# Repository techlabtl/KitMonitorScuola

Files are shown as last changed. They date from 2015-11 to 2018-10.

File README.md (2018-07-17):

## KIT CONSUMARE DI MENO versione2018

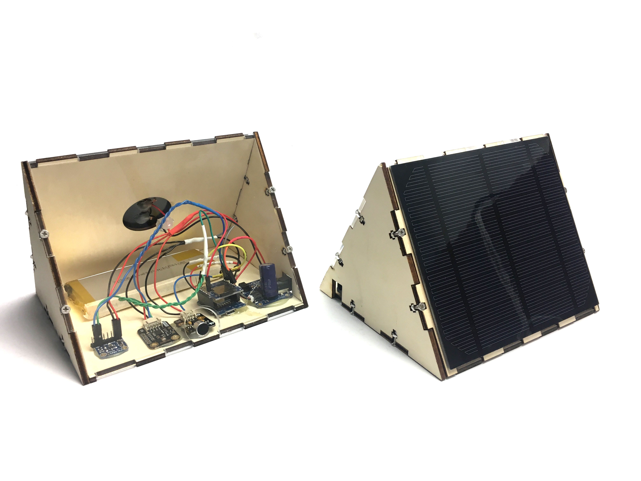
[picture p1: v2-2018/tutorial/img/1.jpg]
Screenshoot


## COMPONENTI
* Wemos
* MicroSD Shield (Optional)
* sd card (Optional)
* BME680
* TSL2561
* ANALOG LIGHT SENS BREAKOUT BOARD

## PINMAP
#### SENSORI I2C -> WEMOS
* sda -> D2
* scl -> D1
* vin -> 3.3V
* gnd -> GND
#### Analog light -> WEMOS
* vcc -> 3.3V
* gnd -> GND
* out -> A0

## Descrizione
la wemos espone una rete wifi chiamata __"Kit Monitoraggio"__

all'indirizzo __192.168.4.1 è presente un webserver che comunica i dati istantanei e quelli medi rilevati da quando la wemos è stata accesa l'ultima volta

## Backup
aggiungendo una shield wemos SD e una scheda SD, vengono automaticamente registrati i dati raccolti.
per risparmiare risorse viene salvata solo la media dei dati degli ultimi 10 minuti.

## Customization
* modificando la variabile __LIGHT_THRESHOLD__ è possibile indicare la soglia sopra la quale la luce viene considerata accesa
* modificando la variabile __SAVE_TIME__ è possibile cambiare la frequenza con cui vengono salvati i dati su sd
* modificando la variabile __SENSOR_TIME__ è possibile cambiare la frequenza con cui vengono letti i sensori
* modificando la variabile __*ssid__ è possibile cambiare il nome della rete wifi esposta

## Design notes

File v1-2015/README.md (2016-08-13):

# KitMonitorScuola
Repository del progetto "Impariamo a consumare di meno.." promosso da Gennaro Fanelli e Finanziato dal MIUR nel 2015.
Nella cartella **Tutorial** trovi le istuzioni per costruire il tuo kit di monitoraggio energertico e nella cartella **Kits** ci sono i file di configurazione dei kit attualmente montati e funzionanti.

Un breve indice:

 * [Istruzioni per comprare e costruirti da te il kit] (#sec1)
 * [Il codice da caricare sull'arduino YUN per leggere i sensori e testare il kit] (#sec2)
 * [Il tutorial per collegare il KIT alla wifi e mandare i dati a plot.ly] (#sec3)
 * [I grafici prodotti da una scuola partecipante al progetto] (#sec4)

### Istruzioni per comprare e costruire da te il kit 
All'interno della cartella [Assemblaggio](https://github.com/paolocavagnolo/KitMonitorScuola/tree/master/Tutorial/Assemblaggio) è presente la lista di materiale necessaria per la realizzazione del kit. Sono presenti anche tutti i link per gli acquisti da [Arduino.cc](https://www.arduino.cc/) e [SeeedStudio](http://www.seeedstudio.com/).

Si sottolinea che la prima scelta è stata quella del kit spagnolo [SmartCitizien](https://smartcitizen.me/)

Inoltre è presente il file per tagliare a laser la basetta e la copertura; da portare in qualsiasi Fablab o Makerspace. In zona si segnalano:
* [TechLab] (http://techlab.tl/)
* [FabLab Torino] (http://fablabtorino.org/)
* [FabLab Settimo] (http://www.fablabsettimo.org/)

Tutti gli altri componenti sono facilmente reperibili in ferramenta.

### Il codice da caricare sull'arduino YUN per leggere i sensori e testare il kit 
Una volta assemblato il kit sarà necessario caricare sopra l'arduino il codice necessario per testare i vari sensori. E' possibile comperare svariate tipologie di sensori e, una volta capito il meccanismo illustrato nella cartella [Configurazione](https://github.com/paolocavagnolo/KitMonitorScuola/tree/master/Tutorial/Configurazione), testarli ed utilizzarli.

### Il tutorial per collegare il KIT alla wifi e mandare i dati a plot.ly 
Il passo successivo è quello di collegare il kit ad internet in modo che possa comunicare con il servizio gratuito on-line [plot.ly](https://plot.ly/
Nella cartella [ConnessioneWifi](https://github.com/paolocavagnolo/KitMonitorScuola/tree/master/Tutorial/ConnessioneWifi) sono presenti i link con i tutorial specifici per ogni passaggio e i codici definitivi da caricare sulla scheda.

### I grafici prodotti da una scuola partecipante al progetto 

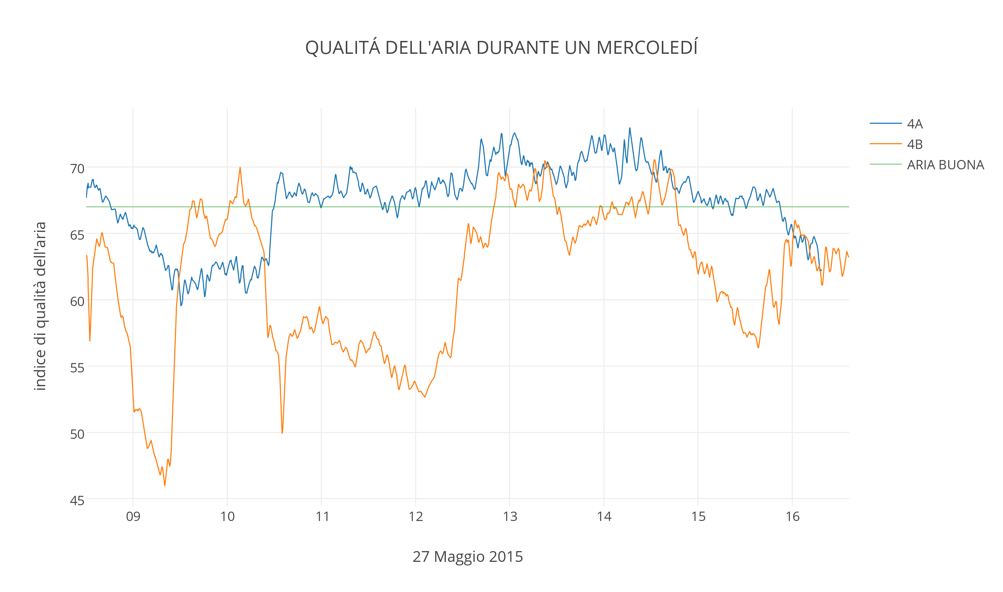
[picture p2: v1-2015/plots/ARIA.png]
Qualita' dell'aria


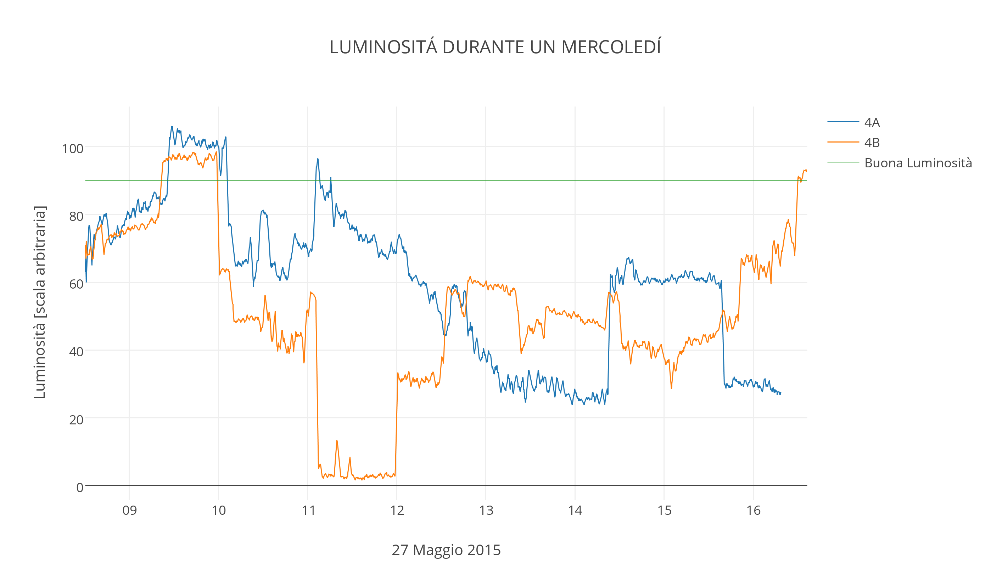
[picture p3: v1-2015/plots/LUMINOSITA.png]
Luminosita'


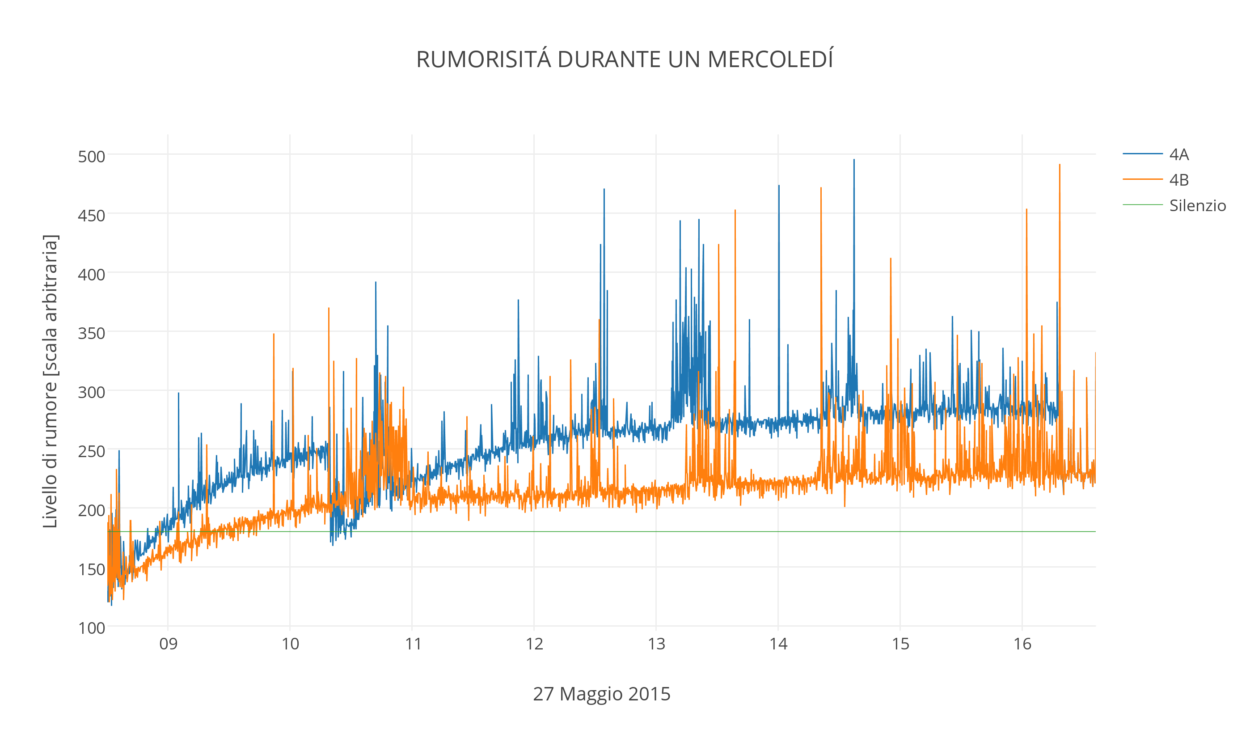
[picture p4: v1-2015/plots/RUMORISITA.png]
Rumorisita'


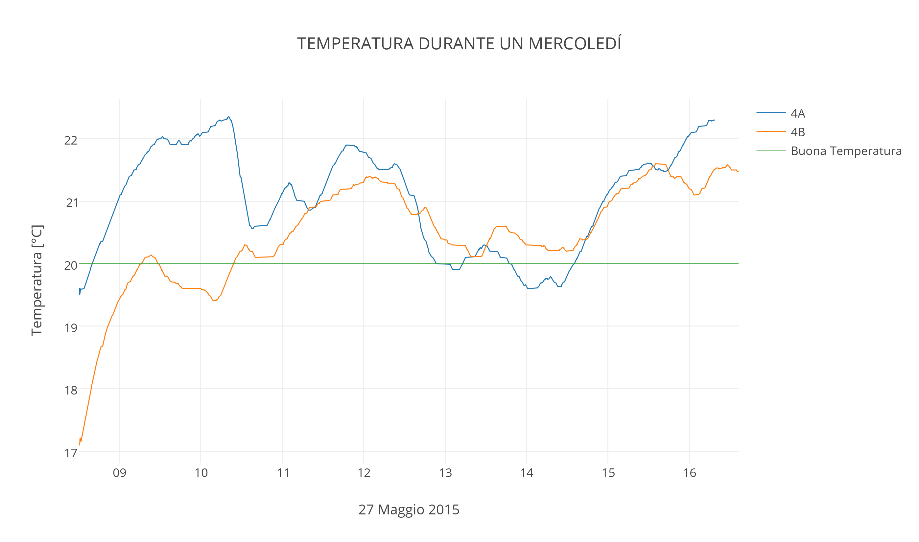
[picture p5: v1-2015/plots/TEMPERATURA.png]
Temperatura


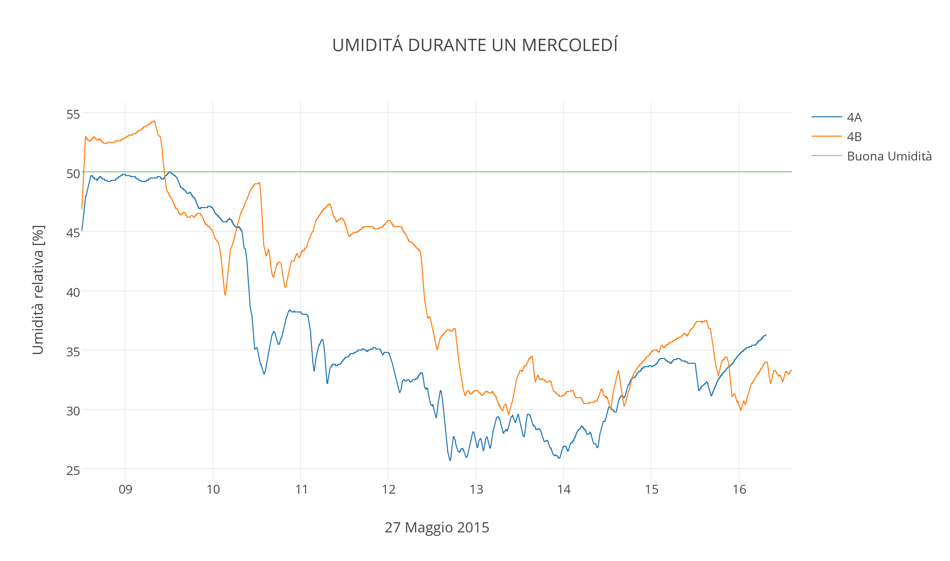
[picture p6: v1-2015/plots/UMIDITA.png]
Umidita'


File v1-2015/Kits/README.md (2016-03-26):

#Guida per la configurazione della yun per renderla un bel client per plotly

Bene, eccoci.
Questa guida raccoglie tutti i passaggi per poter configurare l'arduino YÚN, con i 5 sensori collegati.
L'idea di base è la seguente:

 - Il processore 32U4 presente sulla YÚN verrò fleshato con apposito codice e si occuperà di raccogliere i dati ogni X secondi e scriverli all'interno di due file:
    - **datalog.txt** dove verranno registrati per backup
    - **/collector/arduinoData** che rappresenta il buffer per la comunicazione a plot.ly

 - Il sistema operativo *openWrt* gestirà i rapporti tra i due file e plot.ly.

##Aggiorna il firmware della yun
Trovi qua la guida:

https://www.arduino.cc/en/Tutorial/YunSysupgrade

##Espandi lo spazio del sistema operativo sulla SD

https://www.arduino.cc/en/Tutorial/ExpandingYunDiskSpace

Se no, puoi collegarti in ssh e poi eseguire i seguenti comandi (per avere un disco da 1Gb):

      opkg update
      opkg install e2fsprogs mkdosfs fdisk rsync

      rm -rf /mnt/sda?; umount /dev/sda?

      dd if=/dev/zero of=/dev/sda bs=4096 count=10

      (echo n; echo p; echo 1; echo; echo 1048576; echo w) | fdisk /dev/sda

      rm -rf /mnt/sda?
      umount /dev/sda?

      (echo n; echo p; echo 2; echo; echo; echo w) | fdisk /dev/sda

      rm -rf /mnt/sda?
      umount /dev/sda?

      (echo t; echo 1; echo c; echo w) | fdisk /dev/sda

      mkfs.vfat /dev/sda1
      mkfs.ext4 /dev/sda2

      mkdir -p /mnt/sda1
      mount /dev/sda1 /mnt/sda1
      mkdir -p /mnt/sda1/arduino/www

      rm -rf /mnt/sda?
      umount /dev/sda?

      mkdir -p /mnt/sda2
      mount /dev/sda2 /mnt/sda2
      rsync -a --exclude=/mnt/ --exclude=/www/sd /overlay/ /mnt/sda2/

      rm -rf /mnt/sda?
      umount /dev/sda?

      uci add fstab mount
      uci set fstab.@mount[0].target=/overlay
      uci set fstab.@mount[0].device=/dev/sda2
      uci set fstab.@mount[0].fstype=ext4
      uci set fstab.@mount[0].enabled=1
      uci set fstab.@mount[0].enabled_fsck=0
      uci set fstab.@mount[0].options=rw,sync,noatime,nodiratime
      uci commit

      reboot

se ti servono altre info puoi guardare la guida su:

https://wiki.openwrt.org/doc/howto/extroot

Prima di proseguire dovrai collegare la yun alla rete wifi!

##Installa la libreria di python per plotly

    opkg update
    opkg install python-openssl
    opkg install distribute
    opkg install subversion-client
    easy_install pip
    pip install plotly

##Clona tutti i file che ti servono sulla SD

    svn export https://github.com/paolocavagnolo/KitMonitorScuola/trunk/...
    svn export https://github.com/paolocavagnolo/KitMonitorScuola/trunk/...

Guarda sul file di configurazione **config.param** il path corretto.

##Configura plotly

I parametri di configurazione (da sostituire ai ... li trovi nel file **config.param**.

    python -c "import plotly; plotly.tools.set_credentials_file(username='...', api_key='...')"

cambia il nome di *dataName*, nei seguenti file:

- PRIMOplotterA.py
- plotterA.py

##Configura openwrt

Fai aggiornare automaticamente il software in 2 momenti distinti della giornata, alle 12.00 e alle 19.00

    crontab -e

aggiungi le seguenti righe: ----DA AGGIORNARE---

    00 12 * * * date >> /mnt/sda1/log.log; echo "12.00 upload data" >> /mnt/sda1/log.log; python /mnt/sda1/linino/plotterA.py >> /mnt/sda1/log.log
    00 19 * * * date >> /mnt/sda1/log.log; echo "19.00 upload data" >> /mnt/sda1/log.log; python /mnt/sda1/linino/plotterA.py >> /mnt/sda1/log.log
    00 07 * * * date >> /mnt/sda1/log.log; echo "sync arduino with github" >> /mnt/sda1/log.log; svn export https://github.com/paolocavagnolo/KitMonitorScuola/trunk/Kits/TechLab_1/testKit/arduino/ --force /mnt/sda1/arduino/
    01 07 * * * date >> /mnt/sda1/log.log; echo "sync linino with github" >> /mnt/sda1/log.log; svn export https://github.com/paolocavagnolo/KitMonitorScuola/trunk/Kits/TechLab_1/testKit/linino/ --force /mnt/sda1/linino/

oppure per il secondo:

    00 12 * * * date >> /mnt/sda1/log.log; echo "12.00 upload data" >> /mnt/sda1/log.log; python /mnt/sda1/linino/plotterB.py >> /mnt/sda1/log.log
    00 19 * * * date >> /mnt/sda1/log.log; echo "19.00 upload data" >> /mnt/sda1/log.log; python /mnt/sda1/linino/plotterB.py >> /mnt/sda1/log.log
    00 07 * * * date >> /mnt/sda1/log.log; echo "sync arduino with github" >> /mnt/sda1/log.log; svn export svn export https://github.com/paolocavagnolo/KitMonitorScuola/trunk/Kits/Nasi_2/1D_b/arduino/ --force /mnt/sda1/arduino/
    01 07 * * * date >> /mnt/sda1/log.log; echo "sync linino with github" >> /mnt/sda1/log.log; svn export svn export https://github.com/paolocavagnolo/KitMonitorScuola/trunk/Kits/Nasi_2/1D_b/linino/ --force /mnt/sda1/linino/

attiva crontab:

    /etc/init.d/cron start
    /etc/init.d/cron enable

##Lancia sketch di arduino

    /mnt/sda1/arduino/hex-upload.sh readSensors.cpp.hex

##Crea la cartella collector

    mkdir /mnt/sda1/linino/collector

## Crea il file arduinoData nella cartella collector

    touch /mnt/sda1/linino/collector/arduinoData

##Crea i grafici

Pronti? Partenza..

    python mnt/sda1/linino/PRIMOplotterA.py
    python mnt/sda1/linino/PRIMOplotterB.py

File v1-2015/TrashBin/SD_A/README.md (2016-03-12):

#Guida per la configurazione della yun per renderla un bel client per plotly

Bene, eccoci.
Questa guida raccoglie tutti i passaggi per poter configurare l'arduino YÚNN, con i 5 sensori collegati.
L'idea di base è la seguente:

 - Il processore 32U4 presente sulla YÚN verrò fleshato con apposito codice e si occuperà di raccogliere i dati ogni X secondi e scriverli all'interno di due file:
    - **datalog.txt** dove verranno registrati per backup
    - **/collector/arduinoData** che rappresenta il buffer per la comunicazione a plot.ly

 - Il sistema operativo *openWrt* gestirà i rapporti tra i due file e plot.ly.

##Aggiorna il firmware della yun
Trovi qua la guida:

https://www.arduino.cc/en/Tutorial/YunSysupgrade

##Espandi lo spazio del sistema operativo sulla SD

https://www.arduino.cc/en/Tutorial/ExpandingYunDiskSpace

Se no, puoi collegarti in ssh e poi eseguire i seguenti comandi (per avere un disco da 1Gb):

      opkg update
      opkg install e2fsprogs mkdosfs fdisk rsync

      rm -rf /mnt/sda?
      umount /dev/sda?

      dd if=/dev/zero of=/dev/sda bs=4096 count=10

      (echo n; echo p; echo 1; echo; echo 1048576; echo w) | fdisk /dev/sda

      rm -rf /mnt/sda?
      umount /dev/sda?

      (echo n; echo p; echo 2; echo; echo; echo w) | fdisk /dev/sda

      rm -rf /mnt/sda?
      umount /dev/sda?

      (echo t; echo 1; echo c; echo w) | fdisk /dev/sda

      mkfs.vfat /dev/sda1
      mkfs.ext4 /dev/sda2

      mkdir -p /mnt/sda1
      mount /dev/sda1 /mnt/sda1
      mkdir -p /mnt/sda1/arduino/www

      rm -rf /mnt/sda?
      umount /dev/sda?

      mkdir -p /mnt/sda2
      mount /dev/sda2 /mnt/sda2
      rsync -a --exclude=/mnt/ --exclude=/www/sd /overlay/ /mnt/sda2/

      rm -rf /mnt/sda?
      umount /dev/sda?

      uci add fstab mount
      uci set fstab.@mount[0].target=/overlay
      uci set fstab.@mount[0].device=/dev/sda2
      uci set fstab.@mount[0].fstype=ext4
      uci set fstab.@mount[0].enabled=1
      uci set fstab.@mount[0].enabled_fsck=0
      uci set fstab.@mount[0].options=rw,sync,noatime,nodiratime
      uci commit

se ti servono altre info puoi guardare la guida su:

https://wiki.openwrt.org/doc/howto/extroot

##Installa la libreria di python per plotly

    opkg update
    opkg install python-openssl
    opkg install distribute
    opkg install subversion-client
    easy_install pip
    pip install plotly

##Clona tutti i file che ti servono sulla SD

    svn export https://github.com/paolocavagnolo/KitMonitorScuola/trunk/arduino/ --force
    svn export https://github.com/paolocavagnolo/KitMonitorScuola/trunk/linino/ --force

##Configura plotly

    python -c "import plotly; plotly.tools.set_credentials_file(username='techlabplot', api_key='2dehs2k3sw')"

cambia il nome della ClasseA, nei seguenti file:

- PRIMOplotterA.py
- plotterA.py

    python PRIMOplotterA.py

##Configura openwrt

Fai aggiornare automaticamente il software in 2 momenti distinti della giornata, alle 12.00 e alle 19.00

  crontab -e

aggiungi le seguenti righe:

  00 12 * * * date > /mnt/sda1/SD_A/log.log; python /mnt/sda1/SD_A/plotterA.py > /mnt/sda1/SD_A/log.log
  00 19 * * * date > /mnt/sda1/SD_A/log.log; python /mnt/sda1/SD_A/plotterA.py > /mnt/sda1/SD_A/log.log

attiva crontab:

  /etc/init.d/cron start
  /etc/init.d/cron enable

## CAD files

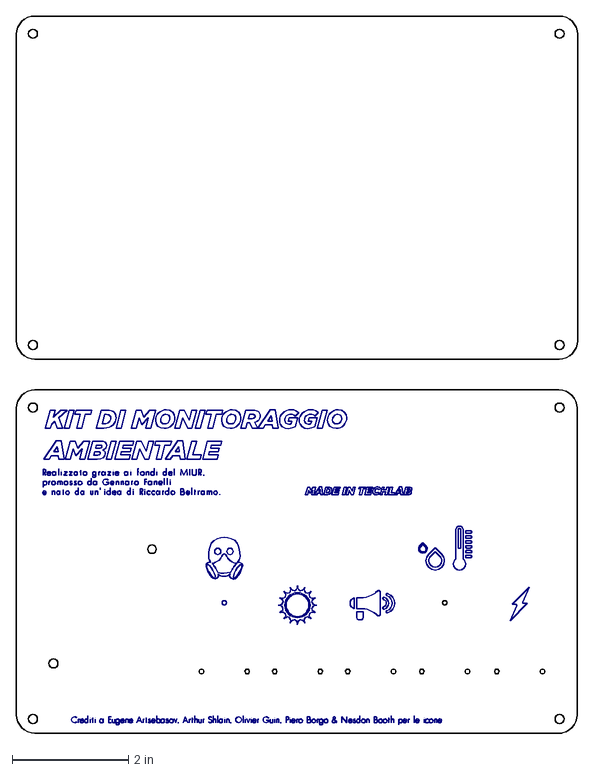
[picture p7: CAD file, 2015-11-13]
v1-2015/Tutorial/Assemblaggio/LaserCut/case.dxf
9.66 x 12.3 in

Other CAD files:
v2-2018/tutorial/Assemblaggio/case50x50.dxf

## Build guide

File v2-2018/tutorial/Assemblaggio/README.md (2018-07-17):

### Consigli per il taglio a laser

Il file contiene i 5 percorsi di taglio per realizzare il kit.
I primi 4 sono tagliati nel multistrato di pioppo 4mm
Il 5° nel plexyglass PMMA 4mm

Per la lavorazione con un laser da 120W, usando il software LaserCut 5.2 io ho usato:
* speed 20
* power 90
* corner power 81

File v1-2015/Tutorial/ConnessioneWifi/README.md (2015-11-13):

## Fin qui tutto bene...

### Inizia il divertimento
Bene!
Hai tra le mani un kit con dei sensori che leggono e stampano in seriale. Come facciamo a mandare questi dati ad un sito internet dedicato proprio alla loro visualizzazione?
2 grandi passi:
 * collegare l'arduino YUN in wifi
 * mandare i dati sul plot.ly

### Collegare l'arduino YUN in wifi
Esistono molte leggende su tutti i vari comportamenti che questa scheda ha quando si connette in wifi.. Diciamo che date le molte variabili presente in una rete wifi casalinga o pubblica è difficile predire tutte le possibilità, quindi vi consiglio di seguire bene tutti i passaggi della seguente guida:

http://www.maffucci.it/2013/10/02/benvenuto-arduino-yun/

La guida è stata scritta per i sistemi operativi OSX, per apple, per Windows 7 c'è questo:

http://www.logicaprogrammabile.it/installazione-arduino-sistema-windows-7/

e ce ne sono molte altre, facili da trovare.

### Mandare i dati su plot.ly
Benissimo.
Adesso avete un piccolo PC collegato ad internet! Se conoscete il protocollo SSH [potete usarlo per connettervi](http://codybonney.com/connecting-to-the-arduino-yun-via-ssh/), per esempio, e vedere com'è fatto il sistema operativo dentro la scheda.

Oppure, potete caricare lo sketch definitivo che manda i dati ad un sito molto interessante che offre un servizio gratuito di visualizzazione dati:

https://plot.ly/

Per capire come funziona dovete completare tutti gli step di questo bellissimo tutorial:

https://github.com/plotly/arduino-api/tree/master/plotly_yun

###

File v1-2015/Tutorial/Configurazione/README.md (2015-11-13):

## Prima configurazione del kit

### Collegamenti
Per configurare il kit bisogna:
* collegare l'arduino yun con un cavo USB - microUSB al proprio PC
* inserire la scheda microSD nell'arduino yun
* inserire la *base shield* sull'arduino yun
* collegare ogni sensore al relativo ingresso analogico

Come faccio a riconoscere i giusti ingressi analogici? 
Basta guardare tra le prime righe di codice, nella cartella test_sensori :)

### Arduino
Scaricatelo da qui:
https://www.arduino.cc/en/Main/Software

e poi avviatelo una volta in modo che si configuri correttamente.

### Librerie
Per utilizzare i sensori serviranno due librerie che ci semplifichino la vita:
le potete trovare qua:

* DHTLib: https://drive.google.com/open?id=0B4KNW3XBN0r0c1QxMjl2dkpQc2c
* Emonlib: https://github.com/openenergymonitor/EmonLib

Per installarle correttamente (basta poco perché Arduino non le riconosca..) dovete:
* scaricare e scompattarle
* copiarle nella cartella **Arduino/Libraries/** che si trova in diversi posti a seconda del vostro sistema operativa, solitamente dentro la cartella **Documenti**

Prima di poterle utilizzare dovrete chiudere e riaprire il software Arduino.

### Primo upload nella scheda!
Adesso siete pronti per scaricare il codice (o copiarlo) ed aprirlo con Arduino. Dopo di che dovrete compiere i seguenti passi
per poterlo inserire nel microchip interno alla scheda:
* Selezionare dal menù **Strumenti** la scheda: Arduino YUN
* Selezionare dal menù **Porta** la scheda Arduino (collegata al PC :)
* Schiacciare il pulsante tondo con la freccia verso destra!

**Per capire cosa fa il codice leggete il README.md nella cartella test_sensori**

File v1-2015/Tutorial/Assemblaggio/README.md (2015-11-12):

## Componenti
Un kit è composto da:
 * 1 [Arduino YUN] (#yun)
 * 1 [Grove Base] (#base)
 * 1 [Sensore qualità aria] (#air)
 * 1 [Sensore temperatura e umidità] (#temp)
 * 1 [Sensore pressione sonora] (#pres)
 * 1 [Sensore di luminosità] (#lum)
 * 1 [Sensore di corrente] (#cor)
 * 1 [Circuito per il sensore di corrente] (#cir)
 * [Materiale per collegamenti e struttura] (#mat)
 
E si presenta così:


### Arduino YUN 


Arduino YUN è un piccolo computerino che ospita una leggera distribuzione di linux; in grado di leggere i valori dei sensori e mandarli ad un sito online in grado di visualizzarli.

**Dove trovarlo**: https://www.arduino.cc/en/Main/ArduinoBoardYun

### Grove Base 


Questa è una scheda che permette di connettere facilmente all'arduino molti sensori

**Dove trovarlo**: http://www.seeedstudio.com/depot/base-shield-v13-p-1378.html?cPath=132_134

### Sensore di qualità dell'aria 


Sensore che misura la presenza di molti inquinanti nell'aria

**Dove trovarlo**: http://www.seeedstudio.com/depot/Grove-Air-quality-sensor-v13-p-2439.html

### Sensore di temperatura e umidità 


Sensore di uso comune, al cui interno sono presenti due sonde.

**Dove trovarlo**: http://www.seeedstudio.com/depot/Grove-TemperatureHumidity-Sensor-Pro-p-838.html

### Sensore di pressione sonora 


Sensore che misura il livello di pressione sonora.

**Dove trovarlo**: http://www.seeedstudio.com/depot/Grove-Sound-Sensor-p-752.html

### Sensore di luminosità 


Sensore che misura il livello di luminosità.

**Dove trovarlo**: http://www.seeedstudio.com/depot/Grove-Luminance-Sensor-p-1941.html

### Sensore di corrente 


Amperometro non invasivo in grado di misurare molto bene i carichi resistivi.

**Dove trovarlo**: http://www.seeedstudio.com/depot/Noninvasive-AC-Current-Sensor-25A-max-p-2055.html

### Circuito per sensore di corrente 


Nel link sottostante è spiegata bene la teoria e la pratica per la realizzazione del circuito.

**Dove trovarlo**: http://www.homautomation.org/2013/09/17/current-monitoring-with-non-invasive-sensor-and-arduino/

### Materiale per collegamenti e struttura 

 * 1 jack femmina 1/4"
 * 1 Alimentatore da 5V - almeno 1.5 Ampere
 * 1 Basetta in legno
 * 1 Copertura in plexiglass
 * 4 distanziali
 * 10 vitine da legno
 * 5 connettori groove

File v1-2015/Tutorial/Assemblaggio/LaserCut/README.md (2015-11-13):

### Consigli per il taglio a laser

Il file contiene sia la basetta che la copertura. 
La copertura è molto semplice.
Nella basetta ho colorato le parti da incidere solamente in BLU; quelle da tagliare in NERO.

L'incisione in questo caso non è una campitura (no engrave), ma semplicemente un taglio con valori molto più leggeri.
Per l'incisione con un laser da 60W, usando il software LaserCut 5.2 io ho usato:
* speed 130
* power 23
* corner power 11

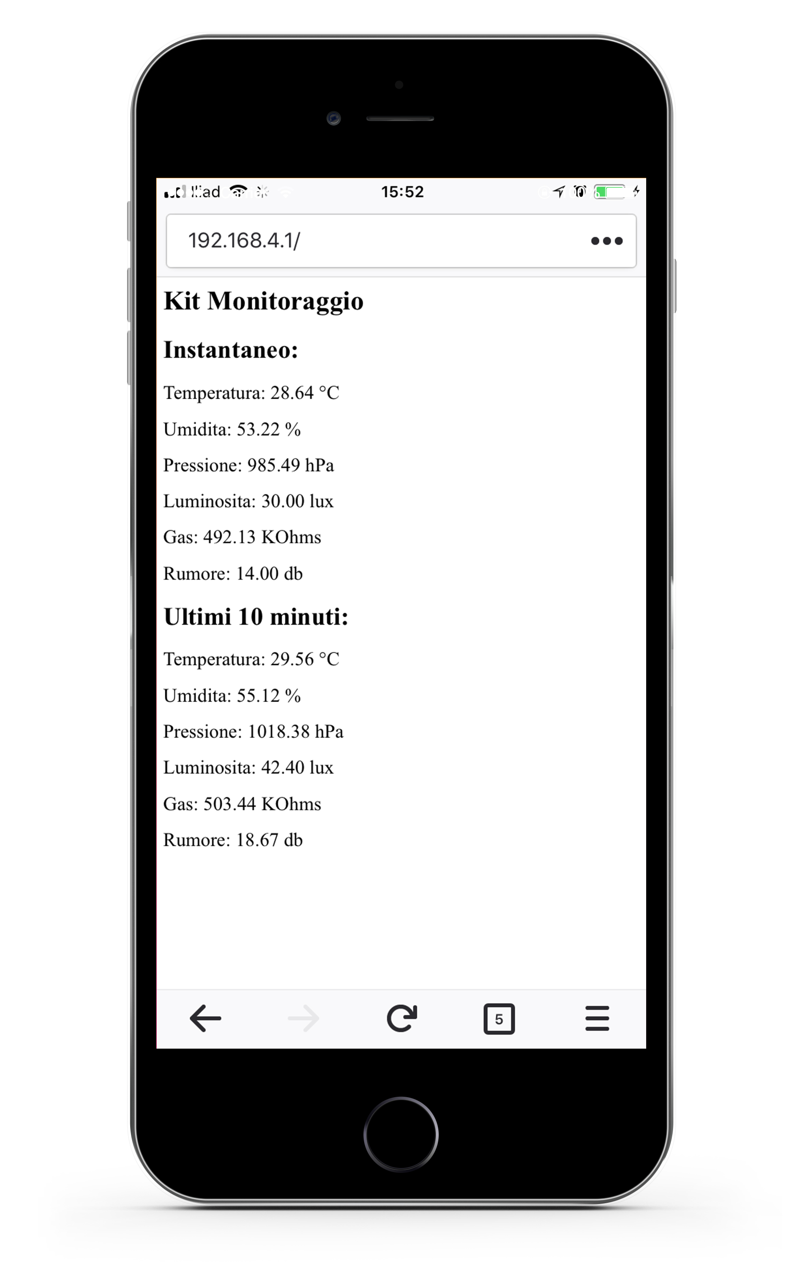
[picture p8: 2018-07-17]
v2-2018/tutorial/img/4.jpg

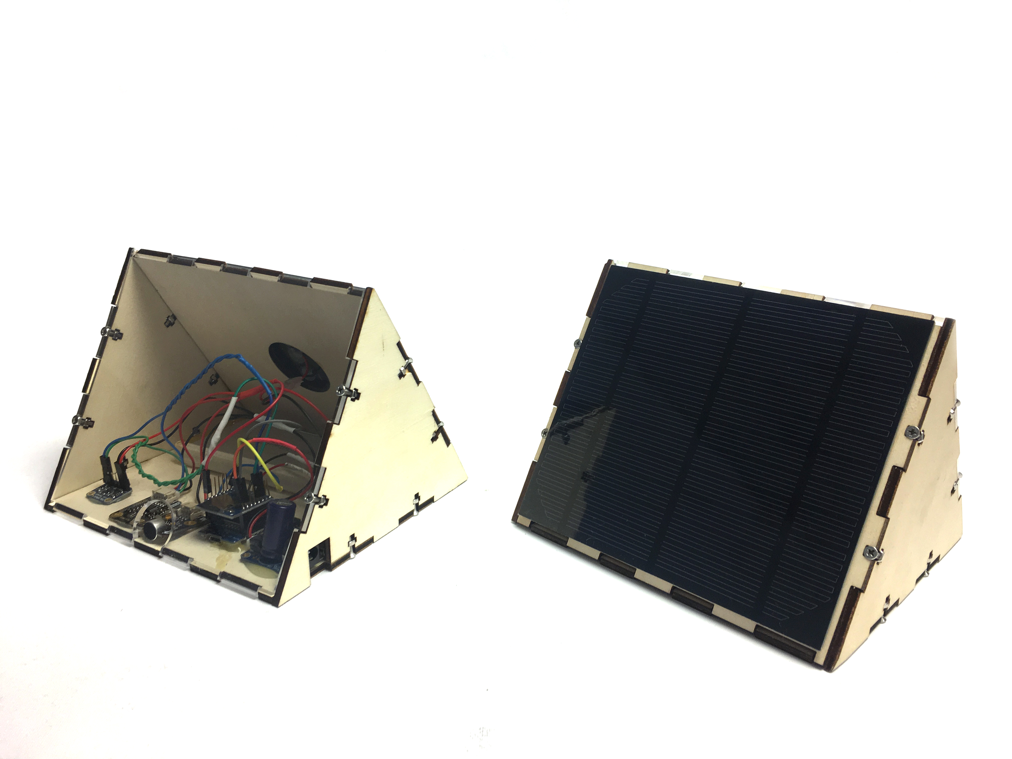
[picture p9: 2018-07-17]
v2-2018/tutorial/img/3.jpg

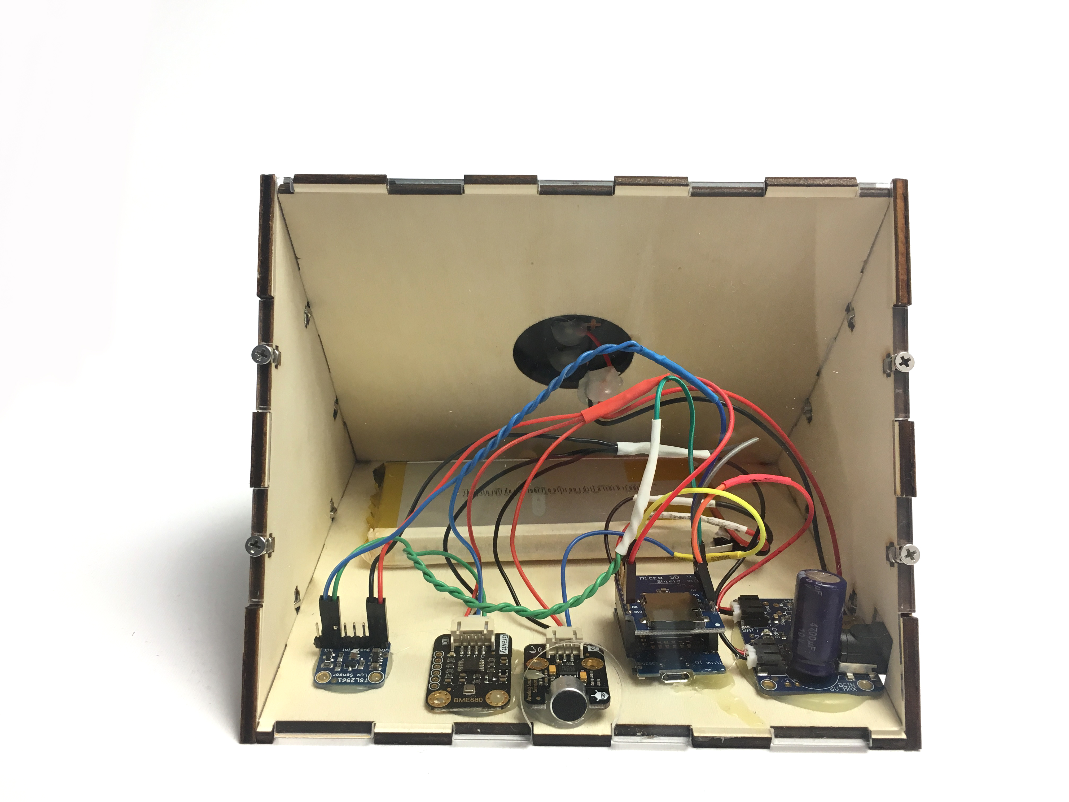
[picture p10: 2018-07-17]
v2-2018/tutorial/img/2.jpg

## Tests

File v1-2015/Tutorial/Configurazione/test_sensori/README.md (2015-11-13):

### Come usare test_sensori.ino

Come vedrete dalla prime righe di codice ogni sensore va collegato ad un preciso ingresso analogico:

* **ingresso A1**: Sensore di pressione sonora
* **ingresso A2**: Sensore di luminosità
* **ingresso A3**: Sensore di temperatura e umidità
* **ingresso A4**: Sensore di corrente

Aprendo il monitor seriale, dopo aver caricato il codice, vedrete apparire questo testo:
```
QUALITA' ARIA: 21
LUMINOSITA': 650
PRESSIONE SONORA: 358
UMIDITA': 42.8
TEMPERATURA: 16.2
CORRENTE: 0.2
```

Provate ad agire sui sensori (alitare su temperatura / umidità o qualità dell'aria basterà per cambiarli - fare rumore - e cambiare 
la luminosità della stanza) e controllate come cambia ogni sensore.

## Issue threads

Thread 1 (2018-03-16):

real time clock

knickita, 2018-03-16:
esponendo noi un server abbiamo bisogno di sapere che ora è in modo da plottare i dati in relazione al tempo. quindi serve un modulo RTC che dica sempre che ora è (anche se non c'è corrente)

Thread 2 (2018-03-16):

conusumi sensore gas

knickita, 2018-03-16:
un sensore gas consuma un bel pò perchè tiene sempre accesa una resistenza.. bisogna cercare altri sensori o limitarne l'uso il più possibile, Davide Gomba forse ha trovato dei sensori di gas che non si basano sulle resistenze

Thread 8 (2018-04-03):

SONOFF

knickita, 2018-04-03:
SONOFF-> da testare e capire come funziona

knickita, 2018-04-03:
la sonoff non è certificabile con un firmware custom caricato, quindi bisogna provare ad usare un sensore di luce posto molto vicino ai neon, per capire quando questi ultimi sono accesi o meno

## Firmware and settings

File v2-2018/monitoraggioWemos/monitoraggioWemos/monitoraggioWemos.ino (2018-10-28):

#include <ESP8266WiFi.h>
#include <WiFiClient.h>
#include <ESP8266WebServer.h>
#include <Wire.h>
#include <SPI.h>
#include <SD.h>
#include <Adafruit_Sensor.h>
#include <Adafruit_BME680.h>
#include "Adafruit_BME680.h"
#include <Adafruit_TSL2561_U.h>

#define BME_SCK 13
#define BME_MISO 12
#define BME_MOSI 11
#define BME_CS 10
#define chipSelect D8


///CUSTOMIZATION VARIABLES
//set the threshold of light on/off in lux
#define LIGHT_THRESHOLD 500
//checks sensors every x milliseconds
#define SENSOR_TIME 1*1000

//saves to SD every x milliseconds
#define SAVE_TIME_SMALL 10*60*1000
//saves to SD every x milliseconds
#define SAVE_TIME_MID 60*60*1000
//saves to SD every x milliseconds
#define SAVE_TIME_LONG 5*60*60*1000

//ssid name
const char *ssid = "Kit Monitoraggio";


Adafruit_BME680 bme;

Adafruit_TSL2561_Unified tsl = Adafruit_TSL2561_Unified(TSL2561_ADDR_FLOAT, 12345);

ESP8266WebServer server(80);

float temperature = 0;
float humidity = 0;
float pressure = 0;
float luminosity = 0;
float gas = 0;
float sound = 0;

float total_small_time[]={0,0,0,0,0,0};
float total_mid_time[]={0,0,0,0,0,0};
float total_long_time[]={0,0,0,0,0,0};

float last_data_saved_small[]={NULL,NULL,NULL,NULL,NULL,NULL};
float last_data_saved_mid[]={NULL,NULL,NULL,NULL,NULL,NULL};
float last_data_saved_long[]={NULL,NULL,NULL,NULL,NULL,NULL};

long int last_saved_small;
long int last_saved_mid;
long int last_saved_long;

boolean is_sd_card_present;

//used to switch an internal resistor to fool the powerbank about current demand and keep it turned on..
bool fool_powerbank = false;

/*
   Go to http://192.168.4.1 in a web browser
*/

String encodeGasMeasure(float kOhms){
  if (kOhms>360){
    return "Ottima";
  }
  if (kOhms>180){
    return "Molto Buona";
  }
  if (kOhms>90){
    return "Buona";
  }
  if (kOhms>45){
    return "Non Buona";
  }
  if (kOhms>22){
    return "Cattiva";
  }
  if (kOhms>11){
    return "Pessima";
  }
  return "Mortale";
}


void handleRoot() {
  String info = "<meta charset=\"utf-8\"/>";
  if (!is_sd_card_present){
    info += "ATTENZIONE! SD CARD NON RILEVATA";
  }
  info += "<h1>Kit Monitoraggio</h1>";
  info += "<h2>Instantaneo:</h2>";
  info += "<p>Temperatura: ";
  info += temperature;
  info += " °C</p><p>Umidita: ";
  info += humidity;
  info += " %</p><p>Pressione: ";
  info += pressure;
  info += " hPa</p><p>Luminosita: ";
  info += luminosity;
  info += " lux</p><p>Qualita' dell'Aria: ";
  info += encodeGasMeasure(gas)+"("+gas;
  info += " KOhms)</p><p>Rumore: ";
  info += sound;
  info += " db</p>";
  
  info += "<h2>Ultimi 10 minuti:</h2>";
  if (last_data_saved_small[0]==NULL){
    info += "<p>In fase di misurazione...</p>";
  }
  else{
    info += "<p>Temperatura: ";
    info += last_data_saved_small[0];
    info += " °C</p><p>Umidita: ";
    info += last_data_saved_small[1];
    info += " %</p><p>Pressione: ";
    info += last_data_saved_small[2];
    info += " hPa</p><p>Luminosita: ";
    info += last_data_saved_small[3];
    info += " lux</p><p>Qualita' dell'Aria: ";
    info += encodeGasMeasure(last_data_saved_small[4])+"("+last_data_saved_small[4];
    info += " KOhms)</p><p>Rumore: ";
    info += last_data_saved_small[5];
    info += " db</p>";
  }

  info += "<h2>Ultimi 60 minuti:</h2>";
  if (last_data_saved_mid[0]==NULL){
    info += "<p>In fase di misurazione...</p>";
  }
  else{
    info += "<p>Temperatura: ";
    info += last_data_saved_mid[0];
    info += " °C</p><p>Umidita: ";
    info += last_data_saved_mid[1];
    info += " %</p><p>Pressione: ";
    info += last_data_saved_mid[2];
    info += " hPa</p><p>Luminosita: ";
    info += last_data_saved_mid[3];
    info += " lux</p><p>Qualita' dell'Aria: ";
    info += encodeGasMeasure(last_data_saved_mid[4])+"("+last_data_saved_mid[4];
    info += " KOhms)</p><p>Rumore: ";
    info += last_data_saved_mid[5];
    info += " db</p>";
  }

  info += "<h2>Ultime 5 ore:</h2>";
  if (last_data_saved_long[0]==NULL){
    info += "<p>In fase di misurazione...</p>";
  }
  else{
    info += "<p>Temperatura: ";
    info += last_data_saved_long[0];
    info += " °C</p><p>Umidita: ";
    info += last_data_saved_long[1];
    info += " %</p><p>Pressione: ";
    info += last_data_saved_long[2];
    info += " hPa</p><p>Luminosita: ";
    info += last_data_saved_long[3];
    info += " lux</p><p>Qualita' dell'Aria: ";
    info += encodeGasMeasure(last_data_saved_long[4])+"("+last_data_saved_long[4];
    info += " KOhms)</p><p>Rumore: ";
    info += last_data_saved_long[5];
    info += " db</p>";
  }
  //ricarica la pagina in automatica dopo 5 secondi, così da avere le informazioni aggiornate
  info += "<script> setTimeout(function(){location.reload();}, 5000);  </script>";
  server.send(200, "text/html", info);

}

void setup() {
  //internal resistor to fool powerbank
  pinMode(D3, OUTPUT);
  pinMode(D4, INPUT_PULLUP);

  delay(1000);
  Serial.begin(115200);
  Serial.println();
  Serial.print("Configuring access point...");
  WiFi.softAP(ssid);

  IPAddress myIP = WiFi.softAPIP();
  Serial.print("AP IP address: ");
  Serial.println(myIP);
  server.on("/", handleRoot);
  server.begin();
  Serial.println("HTTP server started");


  //BME SETUP
  bool status;
  // (you can also pass in a Wire library object like &Wire2)
  status = bme.begin();
  if (!status) {
    Serial.println("Could not find a valid BME280 sensor, check wiring!");
    while (1);
  }
  // Set up oversampling and filter initialization
  bme.setTemperatureOversampling(BME680_OS_8X);
  bme.setHumidityOversampling(BME680_OS_2X);
  bme.setPressureOversampling(BME680_OS_4X);
  bme.setIIRFilterSize(BME680_FILTER_SIZE_3);
  bme.setGasHeater(320, 150); // 320*C for 150 ms


  //TSL SETUP
  if (!tsl.begin())
  {
    /* There was a problem detecting the TSL2561 ... check your connections */
    Serial.print("Ooops, no TSL2561 detected ... Check your wiring or I2C ADDR!");
    while (1);
  }
  tsl.enableAutoRange(true);
  tsl.setIntegrationTime(TSL2561_INTEGRATIONTIME_402MS);

  //SD SETUP
  if (!SD.begin(chipSelect)) {
    Serial.println("ERROR! Card failed, or not present");
    is_sd_card_present = false;
  }
  is_sd_card_present = true;

  last_saved_small = millis();

  for (int i=0;i<(sizeof(total_small_time)/sizeof(float));i++){
    total_small_time[i]=0;
    total_mid_time[i]=0;
    total_long_time[i]=0;
  }

  //updating log file
  String dataString = "!!! sensor reset;from now on: reading every ";
  dataString += SENSOR_TIME;
  dataString += " milliseconds, saving every ";
  dataString += SAVE_TIME_SMALL;
  dataString += " milliseconds\n";
  dataString += "temp °C;Hum %;Pres hPa;Lum lux;gas in KOhms;Rumo db";
  if (is_sd_card_present) {
    File dataFile = SD.open("datalog.txt", FILE_WRITE);
    if (dataFile) {
      dataFile.println(dataString);
      dataFile.close();
    }
    else {
      Serial.println("error opening datalog.txt");
    }
  }
}

void loop() {
  server.handleClient();
  readSensors();

  //update small medium
  if (millis() - last_saved_small > SAVE_TIME_SMALL) {
    if (is_sd_card_present) {
      saveToSd();
    }
    last_saved_small = millis();
    float kk = float(SAVE_TIME_SMALL) / float(SENSOR_TIME);
    kk=ceil(kk/2.0f);
    for (int i=0;i<(sizeof(total_small_time)/sizeof(float));i++){
      last_data_saved_small[i]=total_small_time[i]/kk;
      total_small_time[i]=0;
    }
  }

  //update mid medium
  if (millis() - last_saved_mid > SAVE_TIME_MID) {
    last_saved_mid = millis();
    float kk = float(SAVE_TIME_MID) / float(SENSOR_TIME);
    kk=ceil(kk/2.0f);
    for (int i=0;i<(sizeof(total_mid_time)/sizeof(float));i++){
      last_data_saved_mid[i]=total_mid_time[i]/kk;
      total_mid_time[i]=0;
    }
  }
  
  //update long medium
  if (millis() - last_saved_long > SAVE_TIME_LONG) {
    last_saved_long = millis();
    float kk = float(SAVE_TIME_LONG) / float(SENSOR_TIME);
    kk=ceil(kk/2.0f);
    for (int i=0;i<(sizeof(total_long_time)/sizeof(float));i++){
      last_data_saved_long[i]=total_long_time[i]/kk;
      total_long_time[i]=0;
    }
  }

  delay(SENSOR_TIME);
  fool_powerbank = !fool_powerbank;
  digitalWrite(D3, fool_powerbank);

}

void saveToSd() {
  String dataString = "";
  float kk = float(SAVE_TIME_SMALL) / float(SENSOR_TIME);
  kk=ceil(kk/2.0f);
  for (int i=0;i<(sizeof(total_small_time)/sizeof(float));i++){
    dataString += String(total_small_time[i] / kk) + ";"; 
  }

  File dataFile = SD.open("datalog.txt", FILE_WRITE);
  if (dataFile) {
    dataFile.println(dataString);
    dataFile.close();
  }
  else {
    Serial.println("error opening datalog.txt");
  }
}

void readSensors() {
  if (! bme.performReading()) {
    Serial.println("Failed to perform reading :(");
    temperature = 0;
    humidity = 0;
    pressure = 0;
    gas = 0;
  }
  else {
    temperature = bme.temperature;
    humidity = bme.humidity;
    pressure = bme.pressure / 100.0F;
    gas = bme.gas_resistance / 1000.0;
  }

  /* Get a new sensor light event */
  sensors_event_t event;
  tsl.getEvent(&event);
  luminosity = event.light;

  sound = 0;
  for (int i = 0; i < 100; i++) {
    float k = analogRead(0);
    if (k > sound) {
      sound = k;
    }
    delay(1);
  }

  //update total variables
  total_small_time[0] += temperature;
  total_small_time[1] += humidity;
  total_small_time[2] += pressure;
  total_small_time[3] += luminosity;
  total_small_time[4] += gas;
  total_small_time[5] += sound;

  total_mid_time[0] += temperature;
  total_mid_time[1] += humidity;
  total_mid_time[2] += pressure;
  total_mid_time[3] += luminosity;
  total_mid_time[4] += gas;
  total_mid_time[5] += sound;

  total_long_time[0] += temperature;
  total_long_time[1] += humidity;
  total_long_time[2] += pressure;
  total_long_time[3] += luminosity;
  total_long_time[4] += gas;
  total_long_time[5] += sound;
}

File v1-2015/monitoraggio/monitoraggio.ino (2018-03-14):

/**
 * DOCS: 
 *  https://github.com/arduino-libraries/WiFi101/
 */


#include <SPI.h>
#include <WiFi101.h>


// Settings & vars for the AP
char ssid[] = "mkr1000";
char pass[] = "password"; // (not supported yet)
int wifi_status = WL_IDLE_STATUS;

// Settings and vars for the HTTP server
int http_port = 81;
WiFiServer http_server(http_port);
WiFiClient http_client;

// Settings and vars for the relays
byte PIN_relay_pump = 3;
byte relay_pump_status = 0;

byte debug_mode = 1;

void wifi_connect_as_ap() {
  // Is it IDLE ?
  if (wifi_status == WL_IDLE_STATUS) {
    // Try to connect
    wifi_status = WiFi.beginAP(ssid);
    // Wait 10 seconds for connection
    delay(4000);
    _debug_wifi_status();
    // Is it connected?
    wifi_connect_as_ap();
  }
}


void setup() {
  // Setup Serial
  while (!Serial);
  delay(1000);
  Serial.begin(9600);

  // Check for the presence of the shield
  if (WiFi.status() == WL_NO_SHIELD) {
    Serial.println("WiFi shield not present");
    while (true);       // don't continue
  }

  // Create the AP
  wifi_connect_as_ap();

  // Start the HTTP server
  http_server.begin();

  // Init the relay board
  pinMode(PIN_relay_pump, OUTPUT);
  digitalWrite(PIN_relay_pump, LOW);
}

byte _is_a_get_request(String txt) {
  String tmp = _get_request_path(txt);
  if (tmp == "N/A") {
    return 0;
  }
  return 1;
}

/**
 * @returns "N/A" if txt is not the right header 
 */
String _get_request_path(String txt) {
  if (txt.endsWith("HTTP/1.1")) {
    txt = txt.substring(0, txt.indexOf("HTTP/1.1"));
    if (txt.startsWith("GET")) {
      txt = txt.substring(3);
      txt.trim();
      Serial.println("Requesting " + txt); 
      return txt;
    }
  }
  return "N/A";
}

String _html_show_on_off_status(int status) {
  if (status == 0) {
    return "<span style='color:red;'><strong>OFF</strong></span>";
  }
  return "<span style='color:green;'><strong>ON</strong></span>";
}

void process_http_request(String path) {
  if (path == "/") {
    http_client.println("Status Relay: "+_html_show_on_off_status(relay_pump_status));
    http_client.println("<hr>Actions: <ul>");
    http_client.println("<li><a href='/pump_relay_on'>START Pump Relay</a></li>");
    http_client.println("<li><a href='/pump_relay_off'>STOP Pump Relay</a></li>");
    http_client.println("</ul>");
  } else if (path == "/pump_relay_off") {
    http_client.println("Pump Relay OFF");
    http_client.println("<hr>[<a href='/'>Back to Index</a>]");
    digitalWrite(PIN_relay_pump, LOW);
    relay_pump_status = 0;
  } else if (path == "/pump_relay_on") {
    http_client.println("Pump Relay ON");
    http_client.println("<hr>[<a href='/'>Back to Index</a>]");
    digitalWrite(PIN_relay_pump, HIGH);
    relay_pump_status = 1;
  } else {
    http_client.println("404");
  }
}

void process_http_requests() {
  // Listen for incoming http_clients
  http_client = http_server.available();
  byte tmp_request_is_a_get_request = 0;
  String tmp_get_request_line = "";

  if (http_client) {                             // if you get a http_client,
    Serial.println("New client connected.");           // print a message out the serial port
    String currentLine = "";                // make a String to hold incoming data from the http_client
    while (http_client.connected()) {            // loop while the http_client's connected
      if (http_client.available()) {             // if there's bytes to read from the http_client,
        char c = http_client.read();             // read a byte, then
        // Serial.write(c);                    // print it out the serial monitor
        if (c == '\n') {
          // If the current line is blank, you got two newline characters in a row.
          // that's the end of the client HTTP request, so send a response:
          if (currentLine.length() == 0) {
            // HTTP headers always start with a response code (e.g. HTTP/1.1 200 OK)
            // and a content-type so the client knows what's coming, then a blank line:
            http_client.println("HTTP/1.1 200 OK");
            http_client.println("Content-type:text/html");
            http_client.println();
            if (tmp_request_is_a_get_request == 1) {
              process_http_request(_get_request_path(tmp_get_request_line));
            }
            break;
          }
          
          // We don't really care about other headers .. just the /GET ones
          if (_is_a_get_request(currentLine)) {
            tmp_request_is_a_get_request = 1;
            tmp_get_request_line = currentLine;
          }
          // Clear the currentLine buffer
          currentLine = "";
        }
        else if (c != '\r') {
          // Add to the currentLine buffer
          currentLine += c;
        }
      }
    }
    // close the connection:
    http_client.stop();
    Serial.println("Client disconnected.");
  }
}


void loop() {
  process_http_requests();
  
}











////////////////////////
// Non-core functions //
////////////////////////

void _debug_wifi_status() {
  if (debug_mode == 1) {
    // print the SSID of the network you're attached to:
    Serial.print("SSID: ");
    Serial.println(WiFi.SSID());
  
    // print your WiFi shield's IP address:
    IPAddress ip = WiFi.localIP();
    Serial.print("IP Address: ");
    Serial.println(ip);
  
    // print the received signal strength:
    long rssi = WiFi.RSSI();
    Serial.print("signal strength (RSSI):");
    Serial.print(rssi);
    Serial.println(" dBm");
    // print where to go in a browser:
    Serial.print("To see this page in action, open a browser to http://");
    Serial.print(ip);
    Serial.print(":");
    Serial.print(http_port);
    Serial.println();
  }    
}

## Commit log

2015-11-13 Aggiunto il file case.dxf per la taglio laser
    [case.dxf]
2015-11-13 Aggiunto il nuovo file case.dxf per la taglio laser
    [case.dxf]
2016-03-11 tolto plotly da arduino
2016-03-12 change name
    [arduino.param]
2016-03-12 change place of datalog.txt to arduino
    [arduino.param]
2016-03-12 fix arduino
2016-03-12 fix arduino wait time
    [readSensors.ino]
2016-03-14 big organization change
    [arduino.param, case.dxf, config.param]
2016-03-14 add vittone
    [arduino.param, config.param]
2016-03-14 fix name Quarini in 3E
    [arduino.param, config.param]
2016-03-14 fix andezeno
    [arduino.param, config.param]
2016-03-14 add current sensor to andezeno
2016-03-15 fix path sda1
    [arduino.param]
2016-03-15 fix B kit
    [arduino.param]
2016-03-16 aggiunta via Fea
    [arduino.param, config.param]
2016-03-21 add Nasi_2
    [arduino.param, config.param]
2018-05-08 implemented I2C sensors
2018-07-10 fixed wrong datalog values
    [monitoraggioWemos.ino]
2018-07-17 re-organize REPO
    [arduino.param, case.dxf, case50x50.dxf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]
2018-07-17 Repo re-order
    [arduino.param, case.dxf, case50x50.dxf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]
2018-07-17 scheda utilizzo
    [case50x50.dxf]
2018-10-28 aggiunta scala di valori comprensibile per la misurazione della qualità dell'aria
